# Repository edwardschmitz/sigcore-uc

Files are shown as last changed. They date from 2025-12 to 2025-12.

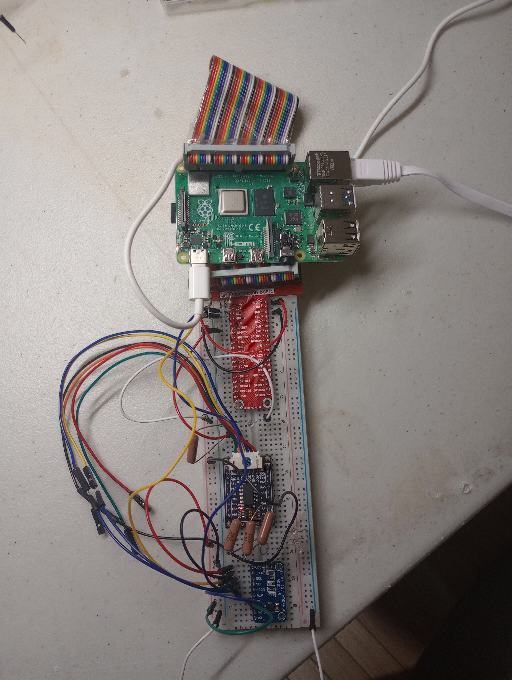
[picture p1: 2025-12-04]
docs/Images/test-pi-ADC.jpg

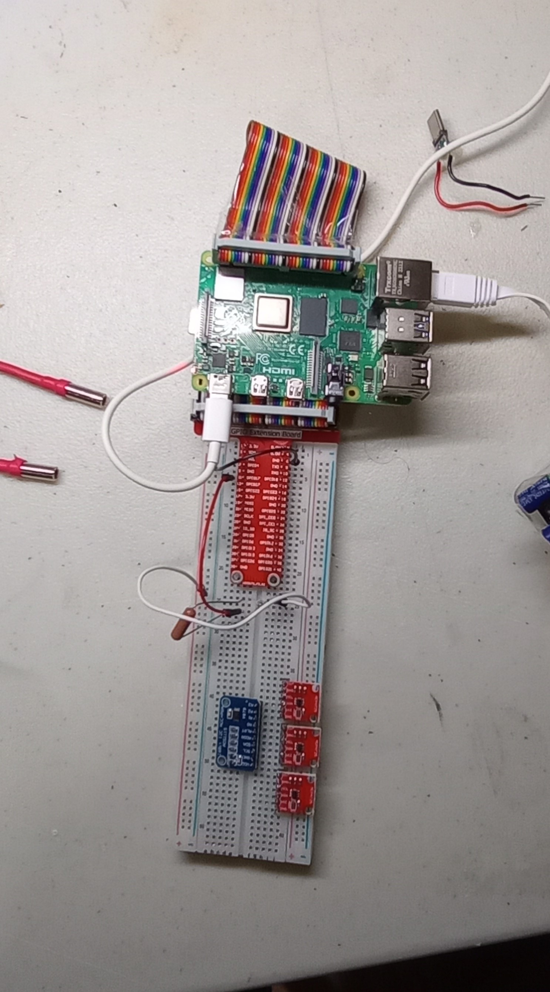
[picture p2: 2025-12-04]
docs/Images/pi-setup.jpg

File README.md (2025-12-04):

# SigCore UC – Universal Controller

**Status:**    In Development  
**Version:**   revA (prototype phase)  
**Runs on:**   Raspberry Pi OS (64-bit) with a .NET 8-based server and a C#/WPF Control Panel for Windows.

SigCore UC is a modular, high-precision universal I/O controller designed for engineers, developers, and integrators working in automation, control systems, and experimentation.

It supports a broad range of analog, digital, and current-loop signals, and is built to be both powerful and transparent—from PCB to Python.

---

## Key Features

- **Analog Inputs**
  - Millivolt to 10V input range
  - 4–20 mA loop support
  - Configurable filtering and calibration
- **Digital Inputs**
  - Logic level support from 3V to 30V
  - Built-in protection and detection
- **Relay Outputs**
  - High-current mechanical and solid-state options
  - Default-state configuration and software override
- **Analog Outputs**
  - Voltage and PWM output modes
- **Communication**
  - Ethernet 
  - Modbus and Web API integration
- **Extensibility**
  - Python and C# libraries
  - Firmware auto-update

---

## License

[MIT License](LICENSE) — open for inspection, modification, and contribution.

---

## About This Repo

SigCore UC is the successor to the [D88A42 Prototype](https://github.com/edwardschmitz/D88A42-Prototype).  
It brings forward lessons learned and raises the ceiling for custom I/O control systems.

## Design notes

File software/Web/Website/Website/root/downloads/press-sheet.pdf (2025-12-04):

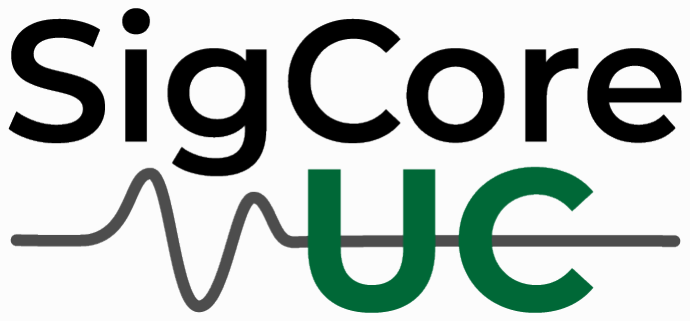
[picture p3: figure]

# Universal Controller

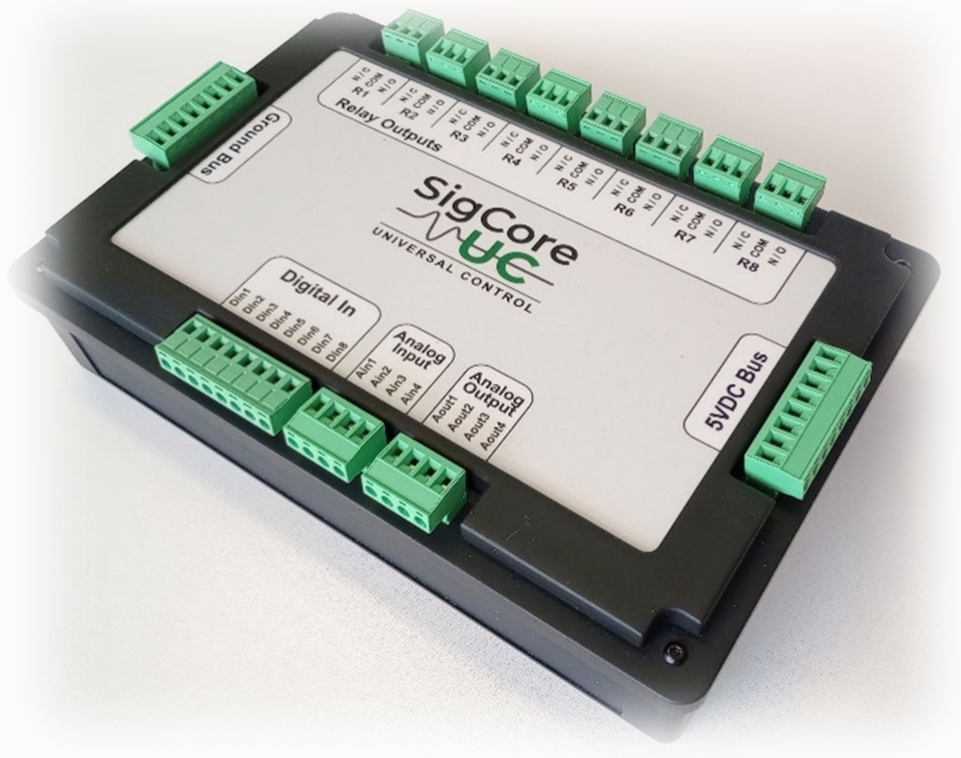
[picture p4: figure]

## A Complete Industrial Control and Data Collection System

SigCore UC is a fully functional industrial control and data collection system. Unlike development boards or expansion modules, SigCore UC is a complete, ready-to-deploy solution — combining rugged hardware with powerful software in one package.
- 8 Relay Outputs – switch equipment and high-current loads
- 8 Universal Digital Inputs – ON: 2–24 VDC, OFF: 0–0.5 VDC
- 4 Calibrated Analog Inputs – voltage or current, with filtering and engineering units
- 4 Analog Outputs – voltage or PWM
- Built-in PID Control Loops – no extra coding required
- Modbus TCP Server – plus .NET and Python libraries
- Control Panel Software – full operational control, including PID settings
- Data Logging – record process data for analysis and optimization Evaluation units are available now.
For review samples, specs, and high-resolution images, please contact: Edward Schmitz
■ en Z em | SigCore UC
■ edwardschmitzsoftware@hotmail.com
■ 805-650-2101
■ https://sigcoreuc.com
________________________________________________________________________ sigcoreuc.com

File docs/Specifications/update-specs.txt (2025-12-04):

REQUIREMENTS OF THE AUTO-UPDATE SYSTEM
=======================================

A. BUILDER (PC-side)
--------------------

A1. Packaging
    - A working SCU archive creator exists.
    - Files are copied into the package from the update source directory.
    - SCU format is implemented: header + file entries + data blocks.
    - Permissions may or may not be preserved depending on OS behavior.
    - Current implementation appears stable but not fully validated.

A2. Manifest Generation
    - Manifest.json is produced.
    - It includes:
        - hardware_rev
        - latest_version
        - versions array
        - SHA-256 hash
        - signature (string produced by builder)
        - URL for update download
    - Manifest.sig is produced using the private key.
    - Manifest fingerprints and version selection appear correct.

A3. Signing
    - SCU file is signed with the private key.
    - Manifest is signed with the private key.
    - Signatures are stored next to their files.
    - Validation steps have not yet been fully tested against corrupted files.

A4. Output Structure
    - Builder writes output into: update/<revision>/<version>/
    - Folder contains:
        - update.scu
        - update.scu.sig
        - manifest.json
        - manifest.sig
    - No automatic cleanup or pruning of old versions exists.

A5. Reliability
    - Builder behaves consistently for known inputs.
    - No automated tests are in place.
    - Error-handling is minimal but functional.
    - Previous versions are not overwritten.

B. LAUNCHER (Pi-side)
----------------------

B1. Update Detection
    - Reads identity.json to determine hardware revision.
    - Constructs URL based on revision.
    - Retrieves manifest.json from remote server.
    - Compares local version vs manifest.latest_version.
    - Currently supports manual testing but not scheduled execution.

B2. Manifest Verification
    - Public key is stored on the Pi.
    - Manifest.sig verification logic is implemented.
    - Verification must pass before continuing.
    - No fallback behavior is defined for malformed manifests.

B3. Download and Validation
    - Launcher downloads update.scu only when needed.
    - SCU signature verification exists.
    - SCU file is checked against manifest hash.
    - Error handling exists but needs strengthening.

B4. Extract and Stage
    - Staging directory: /opt/sigcore/staging
    - Extracts SCU contents into staging.
    - Directory structure is preserved.
    - Validation of required files is not fully implemented.

B5. Apply Update
    B5a. System Prep
        - Stops SigCore Server and WebBridge manually (logic exists but is not final).
        - Remounts filesystem read-write.
        - No versioned backup directory exists yet, but placeholder logic is in place.

    B5b. File Deployment
        - Copies binaries to /opt/sigcore/.
        - Copies website files to /var/www/html/.
        - Writes new version to identity.json.
        - Some deployments still done with shell commands wrapped in code.

    B5c. Cleanup
        - Remounts filesystem read-only.
        - Restarts SigCore Server and WebBridge.
        - Staging directory removed on success.

B6. Failure Handling
    - Verification failures stop the update.
    - Apply failures cause early-return behavior.
    - Automated rollback logic is not fully implemented.
    - System safety behavior has not been fully validated.

B7. Logging
    - Console logging exists.
    - No persistent log file yet.
    - Intended future path: /var/log/sigcore/update.log.

B8. Manual Control
    - Command-line “run once” behavior works now.
    - No CLI arguments for status yet.
    - Launcher is not yet registered as a system service.

SIGCORE UPDATE BUILDER — FILE PURPOSES
======================================

A. ROOT BUILDER FILES
---------------------

Program.cs
    - Entry point for the SigCore Update Builder.
    - Validates that 4 arguments were provided:
        - revision
        - version
        - notes
        - private_key.pem
    - Instantiates UpdateBuilder with the given parameters.
    - Executes builder.Run() to perform the entire build process.
    - Contains no build logic — purely orchestration.

UpdateBuilder.cs
    - Central orchestrator for building a complete SCU-based update release.
    - Responsibilities:
        - Stores revision, version, notes, and private key path.
        - Defines absolute paths for:
            - sigcoreserver executable
            - WebBridge executable
            - local website root directory
            - public key for fingerprinting
        - Creates a temporary build root (temp directory).
        - Creates destination paths:
            - /opt/sigcore
            - /var/www/html
        - Copies:
            - sigcoreserver → opt/sigcore/sigcoreserver
            - WebBridge → opt/sigcore/WebBridge
            - Website contents → var/www/html/**
        - Creates staging output directory:
            C:\Users\eddie\OneDrive\Documents\sigcore\updates\<revision>\<version>\
        - Invokes ScuArchive.Create() to produce update.scu
        - Extracts update.scu into a verify_extract/ folder for self-validation
        - Signs update.scu into update.scu.sig
        - Constructs manifest.json containing:
            - hardware_rev
            - latest_version
            - public_key_fingerprint
            - versions array (with all metadata)
        - Saves manifest.json
        - Signs manifest.json into manifest.sig
        - Prints summary of generated files
    - Includes helpers:
        - CopyFile()
        - CopyDirectory()
    - Entire update packaging workflow lives here.

B. COMMON "UPDATE" LIBRARY FILES
--------------------------------

FingerprintHelper.cs
    - Computes a SHA-256 fingerprint of a PEM public key.
    - Loads RSA key from PEM.
    - Exports the DER-encoded SubjectPublicKeyInfo block.
    - Hashes the DER with SHA-256.
    - Returns lowercase hex fingerprint string.
    - Used to embed public key fingerprint inside manifest.json.
    - Prints the fingerprint to console for debug visibility.

HashHelper.cs
    - Provides SHA-256 hashing utilities.
    - Sha256File(path)
        - Opens file as a stream.
        - Hashes contents.
        - Returns lowercase hex SHA-256 string.
    - Sha256Bytes(data)
        - Hashes in-memory byte array.
    - Internal BytesToHex()
        - Converts byte[] to lowercase hex.
    - Used for SCU archive hashing inside the manifest.

ManifestModel.cs
    - Full data model for manifest.json (serialized/deserialized via Newtonsoft.Json).
    - Top-level fields:
        - hardware_rev
        - latest_version
        - public_key_fingerprint
        - versions[] array
    - VersionEntry fields:
        - version
        - release_date
        - hash_sha256
        - signature (URL to update.scu.sig)
        - url (URL to update.scu)
        - notes
        - executables (list of files the launcher must make executable)
    - Methods:
        - Load(path)
        - Save(path)
    - Used directly by UpdateBuilder when constructing manifest.json.

ScuArchive.cs
    - Implements the SCU1 archive format used by SigCore updates.
    - Magic header: "SCU1"
    - Create(rootFolder, outputFile)
        - Scans all files under rootFolder (recursive)
        - Writes:
            - Magic ("SCU1")
            - File count
            - For each file:
                - Relative path (UTF-8 bytes)
                - Path length (ushort)
                - File length (ulong)
                - Raw file bytes
        - Ensures cross-platform safe relative paths (uses forward slashes)
    - Extract(scuFile, targetFolder)
        - Validates magic header
        - Reads file entries and size metadata
        - Recreates directory structure in targetFolder
        - Restores files exactly as archived
    - GetRelativePath()
        - Uses Uri logic to compute a clean platform-independent path
    - Used by the builder to package **and self-verify** update.scu.

SignatureHelper.cs
    - RSA signing and verification utilities for SCU and manifest.
    - SignFile(privateKeyPem, inputFile, signatureOutputFile)
        - Reads file data.
        - Produces RSA SHA-256 PKCS#1 signature.
        - Writes signature bytes to .sig file.
    - VerifyFile(publicKeyPem, inputFile, signatureFile)
        - Reads both data and signature.
        - Uses RSA public key to verify signature.
    - SignData / VerifyData
        - Core RSA signing logic.
    - LoadPrivateKeyFromPem()
        - Supports encrypted PEM (password currently hardcoded).
        - Supports unencrypted PEM.
    - LoadPublicKeyFromPem()
        - Loads RSA public key.
    - Entire cryptographic signing layer for SCU and manifest is here.

SIGCORE LAUNCHER — FILE PURPOSES
================================

A. DOWNLOAD AND VALIDATION COMPONENTS
-------------------------------------

ManifestDownloader.cs
    - Downloads manifest.json and manifest.sig from the update server.
    - Uses HttpClient to fetch both files as raw byte arrays.
    - Writes results to local disk paths provided by caller.
    - CancellationToken supported for clean shutdown.
    - No validation performed here — strictly a fetch utility.

ManifestValidator.cs
    - Fully validates a manifest + manifest.sig pair.
    - Steps:
        - Uses SignatureHelper.VerifyFile() to confirm manifest.sig is valid.
        - Loads manifest.json into ManifestModel.
        - Computes the fingerprint of the public key on the device.
        - Compares:
            - expectedFingerprint → from Launcher config / identity
            - actualFingerprint → recomputed from local public key
            - manifest.PublicKeyFingerprint → declared by the builder
        - All 3 must match.
    - Purpose:
        - Prevent tampering.
        - Ensure the manifest belongs to the correct hardware revision.
        - Ensure nobody swapped the keypair.

ScuVerifier.cs
    - Responsible for downloading + verifying update.scu and update.scu.sig.
    - DownloadAsync():
        - Downloads SCU and its corresponding signature.
    - Validate():
        - Verifies SHA-256 hash matches manifest entry.
        - Verifies signature matches local public key.
    - Returns boolean success/failure.
    - This is the integrity gate before extraction or installation.

B. INSTALLATION COMPONENTS
--------------------------

AtomicInstaller.cs
    - Applies a verified SCU update safely and atomically.
    - Steps:
        - Deletes existing extractRoot if present.
        - Extracts SCU using ScuArchive.Extract().
        - Locates extracted:
            - opt/sigcore contents
            - var/www/html contents
        - Installs files into live filesystem using atomic replace logic.

    - InstallDirectoryAtomic():
        - Iterates all files under src directory.
        - Maps each to corresponding path under dest.
        - Creates dirs as needed.
        - Uses AtomicReplaceFile() for each file.

    - AtomicReplaceFile():
        - Writes new file as *.new
        - Renames old file to *.bak if present
        - Moves *.new → final filename
        - Removes *.bak if everything succeeded
    - Goal:
        - Never leave corrupted partial files, even after power loss.

C. LOCAL STATE COMPONENTS
-------------------------

InstalledVersionReader.cs
    - Simple utility to read:
        - revision.txt
        - version.txt
    - If file missing:
        - Revision: returns "unknown"
        - Version: returns "0.0.0"
    - Used by UpdateSupervisor / Launcher to compare local state vs manifest.

D. MAIN RUNTIME / PROCESS SUPERVISION
-------------------------------------

Launcher.cs
    - Main runtime supervisor for:
        - SigCoreServer process
        - WebBridge process
    - Fields:
        - serverExe = /opt/sigcore/sigcoreserver
        - bridgeExe = /opt/sigcore/WebBridge
        - revisionPath, versionPath
        - manifest URLs (currently hardcoded to revA)
        - public-key path
        - expectedFingerprint (static for now)
    - RunAsync():
        - Runs update supervisor first.
        - Starts both processes.
        - Enters supervision loop:
            - Every 2 seconds, checks if each process is alive.
            - Restarts dead processes automatically.
        - On token cancellation:
            - Stops both processes gracefully.
    - StartServer() / StartBridge():
        - Launch processes with redirected output.
    - ProcessAlive():
        - Safe check ensuring process hasn't crashed.
    - StopAsync():
        - Kills both server and bridge.
    - Primary role:
        - Keep SigCoreServer and WebBridge alive.
        - Ensure updates are applied before processes start.

E. LAUNCHER VARIANT (OLDER DESIGN)
----------------------------------

LauncherManager.cs
    - An older, alternative launcher architecture.
    - Not used by the current Program.cs entry point.
    - Responsibilities:
        - Loads identity.json
        - Derives revision + version from identity
        - Validates public key presence
        - Invokes UpdateSupervisor with revision-based URLs
        - Starts SigCoreServer then WebBridge
        - Handles Ctrl+C shutdown
        - Terminates both processes on exit
    - Contains:
        - IdentityModel / HardwareInfo / SoftwareInfo inline classes
    - Notes:
        - This may be retired or folded into the new Launcher class.
        - Duplicates responsibilities found in Launcher.cs
        - May be a leftover from a previous architecture.

F. ENTRY POINT
--------------

Program.cs
    - Entry point for the launcher service.
    - Writes startup banner.
    - Registers signal handlers (Ctrl+C, ProcessExit).
    - Allocates CancellationTokenSource.
    - Instantiates Launcher and calls RunAsync().
    - On exceptions:
        - Outputs diagnostic information.
    - On shutdown:
        - Cancels token and allows launcher to stop server + bridge.
    - Contains no update or process logic — purely coordinator.

G. UPDATE EXECUTION LAYER
-------------------------

UpdateRunner.cs
    - Executes the full update cycle once an update has been approved.
    - Responsibilities:
        - Downloads manifest.json + manifest.sig into /tmp/SigCoreUpdate
        - Validates the manifest via ManifestValidator
        - Parses manifest to extract latest version info
        - Downloads update.scu and update.scu.sig
        - Validates:
            - SHA-256 hash
            - RSA signature
        - Extracts update.scu into /tmp/SigCoreUpdateExtract
        - Applies update via AtomicInstaller.Install()
        - Applies executable permissions to any paths listed in manifest.Executables
    - Constructor sets:
        - temp file paths
        - extractRoot for SCU extraction
        - optTarget (e.g. /opt/sigcore)
        - webTarget (e.g. /var/www/html)
    - RunAsync():
        - Returns true on success, false on failure.
        - Primary single-shot update installer.

H. UPDATE SUPERVISION AND DECISION LOGIC
----------------------------------------

UpdateSupervisor.cs
    - Higher-level orchestrator that decides whether an update is needed.
    - Responsibilities:
        - Reads installed revision.txt and version.txt using InstalledVersionReader
        - Downloads manifest.json + manifest.sig
        - Validates manifest via ManifestValidator
        - Uses UpdateDecisionEngine to decide whether update should occur
            - NoUpdate
            - WrongHardwareRevision
            - ManifestInvalid
            - UpdateAvailable
        - If update required:
            - Creates UpdateRunner and executes RunAsync()
        - Logs all decisions
    - Inputs:
        - manifest URLs
        - public key path
        - expected fingerprint
        - installed revision/version files
        - target installation directories
    - Run order:
        - Validate manifest
        - Evaluate decision
        - If update needed, run updater
        - Return true on success or “no update required”
        - Return false on hardware mismatch or failure

UpdateDecisionEngine.cs
    - Decides whether an update is required.
    - Conditions checked:
        - manifest is null → ManifestInvalid
        - hardware revision mismatch → WrongHardwareRevision
        - manifest contains no versions → ManifestInvalid
        - version comparison:
            - installedVersion >= latestVersion → NoUpdate
            - installedVersion < latestVersion → UpdateAvailable
    - Uses VersionComparer to compare semantic-like version strings.
    - Pure logic only — no file I/O.

I. VERSION COMPARISON AND VERSION STAMPING
------------------------------------------

VersionComparer.cs
    - Parses version strings like "1.2.3.4" or "1.0" or "2".
    - Splits on "." and compares each numeric segment.
    - Missing segments treated as zero.
    - Non-numeric segments treated as zero.
    - Returns:
        - -1 if a < b
        - +1 if a > b
        - 0 if equal
    - Used by UpdateDecisionEngine.

VersionStampWriter.cs
    - Writes revision.txt and version.txt *safely* after successful installation.
    - WriteInstalledVersion():
        - Writes both revision and version using atomic-safe logic.
    - WriteSafe():
        - Writes *.new file
        - Moves old file to *.bak
        - Renames *.new to official path
        - Cleans *.bak
    - Ensures partial writes cannot corrupt version tracking.

J. SYSTEMD SERVICE CONTROL
--------------------------

ServiceController.cs
    - Utilities for controlling Linux systemd services.
    - Provides:
        - StopService(name)
        - StartService(name)
        - IsActive(name)
        - IsInactive(name)
    - All functions wrap systemctl commands via /bin/bash.
    - Used for service-based architectures where SigCoreServer/WebBridge may run as systemd units instead of standalone processes.
    - Currently not used in the new Launcher.cs but remains part of legacy support.

K. SUMMARY OF THE UPDATE PIPELINE (FOR CROSS-FILE CONTEXT)
-----------------------------------------------------------

    1. Launcher.cs starts → calls UpdateSupervisor
    2. UpdateSupervisor:
        - Reads installed version/revision
        - Downloads + validates manifest
        - Uses UpdateDecisionEngine to decide if update needed
    3. If update required:
        - Creates UpdateRunner
    4. UpdateRunner:
        - Downloads SCU + sig
        - Validates both
        - Extracts SCU
        - Installs via AtomicInstaller
        - Ensures executables are +x
    5. VersionStampWriter writes new version/revision
    6. Launcher starts services (server + bridge)

SIGCORE AUTO-UPDATE SYSTEM — LIVING SPECIFICATION
=================================================

A. PURPOSE AND GOALS
--------------------
- Provide authenticated, atomic, hardware-aware updates for SigCore UC.
- Ensure updates cannot brick the device.
- Ensure updates cannot be spoofed or tampered with.
- Ensure the update runs BEFORE Server and WebBridge start.
- Ensure Pi runtime always has verified, latest valid software.
- Support offline-safe extraction and atomic replacement.

B. MAJOR COMPONENTS
-------------------
- Builder (Windows): packages, signs, and publishes updates.
- SCU Archive Format: custom binary package containing all update files.
- Manifest: JSON definition describing update metadata and security.
- Launcher (Pi): performs update-check, validation, installation, and process supervision.
- UpdateSupervisor: decision logic for whether and when to update.
- UpdateRunner: performs actual installation.
- AtomicInstaller: performs atomic file replacement.
- Version tracking: revision.txt and version.txt.

C. FILE PATHS (PI SIDE)
-----------------------
- Executables:
    - /opt/sigcore/sigcoreserver
    - /opt/sigcore/WebBridge
- Keys:
    - /opt/sigcore/keys/sigcore_public.pem
- Installed version state:
    - /opt/sigcore/version.txt
    - /opt/sigcore/revision.txt
- Website:
    - /var/www/html
- Temp update locations:
    - /tmp/SigCoreUpdate
    - /tmp/SigCoreUpdateExtract

D. SCU ARCHIVE FORMAT
---------------------
- Magic header: "SCU1"
- uint32: file count
- Per file:
    - ushort: UTF-8 path length
    - bytes: UTF-8 path
    - ulong: file size
    - raw file bytes
- Paths stored normalized with forward slashes.
- Archive contains:
    - opt/sigcore/*    (server, bridge, identities, keys, version files)
    - var/www/html/*   (website)
- Extraction reproduces exact tree.

E. MANIFEST FORMAT
------------------
- hardware_rev (string)
- latest_version (string)
- public_key_fingerprint (hex SHA-256 of DER key)
- versions[]:
    - version
    - release_date
    - hash_sha256 (of update.scu)
    - signature (URL to update.scu.sig)
    - url (URL to update.scu)
    - notes
    - executables[] (files requiring chmod +x)

F. SECURITY MODEL
-----------------
- Builder holds private key (never distributed).
- Pi holds public key in /opt/sigcore/keys/.
- Builder signs:
    - manifest.json
    - update.scu
- Launcher validates:
    - manifest.sig → matches manifest
    - manifest.PublicKeyFingerprint → matches local public key fingerprint
    - SCU hash → matches manifest.hash_sha256
    - SCU signature → matches public key
- Update is rejected if:
    - signature mismatch
    - hash mismatch
    - fingerprint mismatch
    - wrong hardware revision

G. UPDATE DECISION LOGIC
------------------------
- Read installed:
    - revision.txt
    - version.txt
- Download manifest + sig.
- Validate manifest.
- Compare installedRevision vs manifest.hardware_rev:
    - mismatch → reject update.
- Compare installedVersion vs latestVersion using VersionComparer:
    - installed >= latest → no update.
    - installed < latest → update available.

H. UPDATE PROCESS FLOW (PI SIDE)
--------------------------------
1. Launcher starts.
2. Calls UpdateSupervisor.
3. UpdateSupervisor:
    - Reads installed version/revision.
    - Downloads manifest + sig.
    - Validates manifest.
    - Applies UpdateDecisionEngine.
4. If update needed:
    - Create UpdateRunner.
    - Download SCU + sig.
    - Validate hash + signature.
    - Extract SCU into /tmp/SigCoreUpdateExtract.
    - AtomicInstaller.Install() replaces live files.
    - Apply executable flags.
    - Write new version.txt and revision.txt.
5. Launcher starts processes.

I. ATOMIC INSTALLATION RULES
----------------------------
- All installation done under extractRoot.
- For each file:
    - dest.new → write
    - dest.bak → old (if exists)
    - dest.new → dest (move)
    - delete dest.bak
- Ensures:
    - No partial files
    - No corruption from sudden shutdown
    - Every update is all-or-nothing

J. RUNTIME PROCESS SUPERVISION
------------------------------
- Launcher starts:
    - sigcoreserver
    - WebBridge
- Checks every ~2 seconds:
    - if process dead → restart
- On shutdown:
    - kill both processes safely.

K. BUILDER INPUTS & OUTPUTS
----------------------------
Inputs:
    - revision
    - version
    - notes
    - private_key.pem
    - paths to:
        - sigcoreserver binary
        - WebBridge binary
        - website root

Outputs:
    - update.scu
    - update.scu.sig
    - manifest.json
    - manifest.sig

Directory layout:
    update/<revision>/<version>/update.scu
    update/<revision>/<version>/update.scu.sig
    update/<revision>/<version>/manifest.json
    update/<revision>/<version>/manifest.sig

L. VERSIONING RULES
-------------------
- Versions are dot-separated numerics: A.B.C.D
- Extra segments allowed.
- Missing segments treated as zero.
- Non-numeric segments treated as zero.
- VersionComparer decides:
    - <0: installed older
    - =0: equal
    - >0: installed newer

M. CODEBASE SUMMARY (BUILDER)
------------------------------
- Program.cs
    - CLI entry point.
- UpdateBuilder.cs
    - Master build orchestrator.
- FingerprintHelper.cs
    - Public key fingerprint generation.
- HashHelper.cs
    - SHA-256 hashing utilities.
- ManifestModel.cs
    - Manifest JSON schema.
- ScuArchive.cs
    - SCU1 binary packaging/extraction.
- SignatureHelper.cs
    - RSA signing/verification utilities.

N. CODEBASE SUMMARY (LAUNCHER)
------------------------------
- ManifestDownloader.cs
    - Downloads manifest + signature.
- ManifestValidator.cs
    - Validates manifest.signature + fingerprint.
- ScuVerifier.cs
    - Downloads + validates SCU.
- InstalledVersionReader.cs
    - Reads installed version/revision.
- AtomicInstaller.cs
    - Atomic installation logic.
- UpdateDecisionEngine.cs
    - Determines whether update needed.
- VersionComparer.cs
    - Compares semantic versions.
- VersionStampWriter.cs
    - Atomically writes installed version files.
- UpdateSupervisor.cs
    - High-level update logic: decide → run.
- UpdateRunner.cs
    - Performs actual update install.
- ServiceController.cs
    - systemd control utilities (not used in current Launcher).
- Launcher.cs
    - Starts, supervises SigCoreServer + WebBridge.
- Program.cs (launcher)
    - Entry point, shutdown management.

O. REQUIRED ENVIRONMENT
-----------------------
- Linux ARM64 (Pi 4 or Pi 5).
- Read-only root filesystem during operation (future final state).
- Ability to remount rw during update installation (future).
- /opt/sigcore owned by runtime user.
- Web server serves /var/www/html.

P. OPERATIONAL GUIDANCE
-----------------------
- To trigger update manually:
    - Restart launcher.
- To review update errors:
    - Console logs now; future: /var/log/sigcore/update.log.
- To replace public key:
    - Update public key file.
    - Update fingerprint in the builder.
    - Push new manifest with updated fingerprint.
- To test updates:
    - Run builder.
    - Upload update folder to server.
    - Restart launcher on Pi.

Q. FUTURE IMPROVEMENTS
----------------------
- Centralized logging.
- Rollback mechanism.
- Configurable URLs for manifest.
- Non-hardcoded fingerprint.
- Removal of deprecated LauncherManager.
- Option for daily scheduled update checks (service timer).
- Read-only root filesystem enforcement.

ASSISTANT GROUND RULES
----------------------

- Do not use var in any C# code. All types must be explicitly declared.
- Do not insert comments into source code unless explicitly instructed.
- Do not invent or assume the contents of any class, method, or structure. Ask the user when information is missing.
- Do not change method signatures, constructors, or argument structures unless the fix requires it and the user approves.
- Apply fixes one at a time. Do not bundle multiple fixes.
- All code changes must be precise, minimal, and limited to the stated fix.
- Do not alter logging, console output, or filenames unless explicitly instructed.
- Do not assume any library method or helper exists unless the user has shown it. Request missing definitions.
- Do not introduce new dependencies, namespaces, or classes unless explicitly requested.
- When providing updated code files, provide the complete corrected file unless the user requests a fragment.
- Follow sequencing instructions exactly as given.
- Do not reinterpret, generalize, or expand user instructions.
- Do not provide meta-explanations unless requested.
- Apply all stated code-style rules consistently.
- Ask when uncertain.
- When the user requests “text only format,” the assistant must output plain text only,
  without commentary, without markup, without embellishment, and without any structure
  beyond exactly what the user requested and in a code section.

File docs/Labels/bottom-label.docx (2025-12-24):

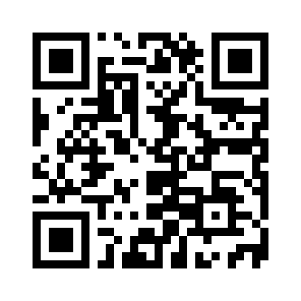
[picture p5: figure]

# SigCore UC

## en Z em Product

Getting Started: | https://sigcoreuc.com/getting-started.html
MAC Address: | 88:A2:9E:3A:0E:C0
Serial Number: | SCUC-000020
Hostname: | scuc-000020
Revision: | revA

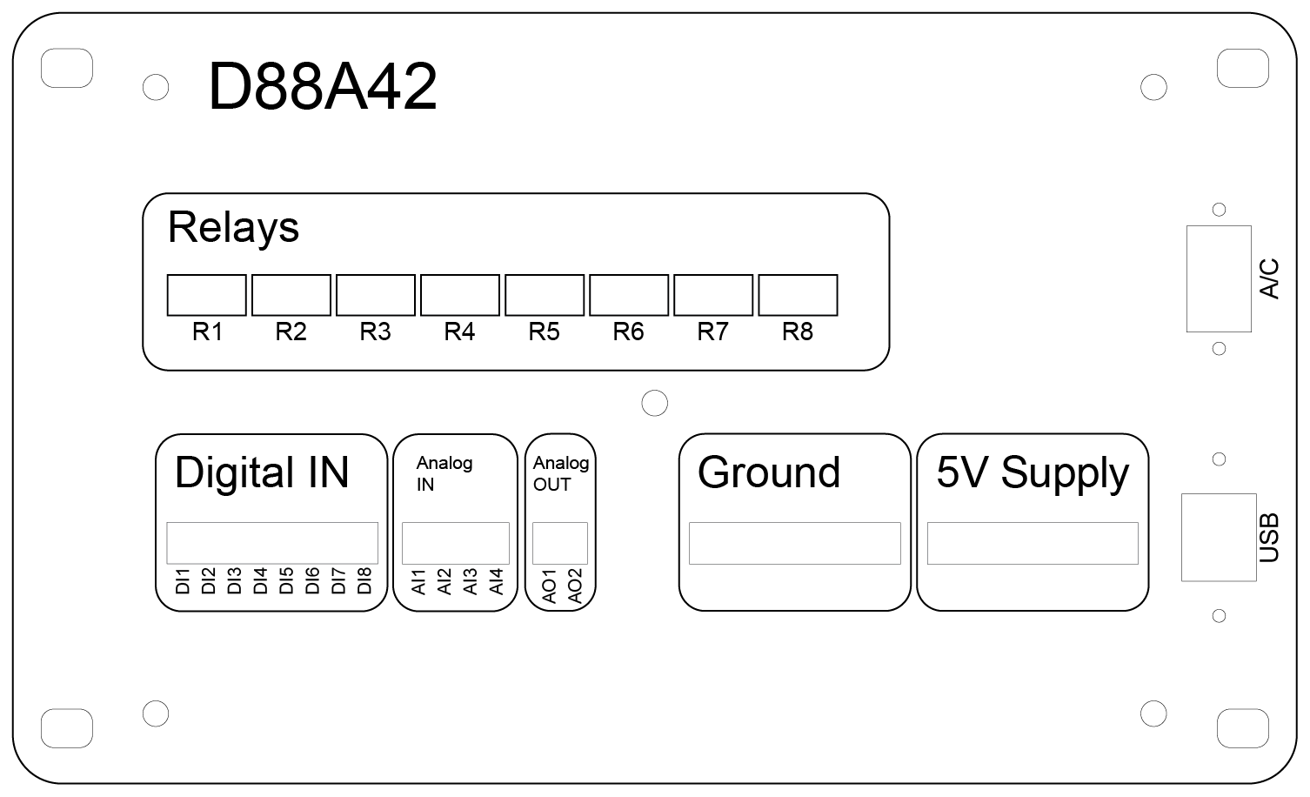
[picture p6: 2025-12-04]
software/Web/Website/Website/root/images/LidDesign.png

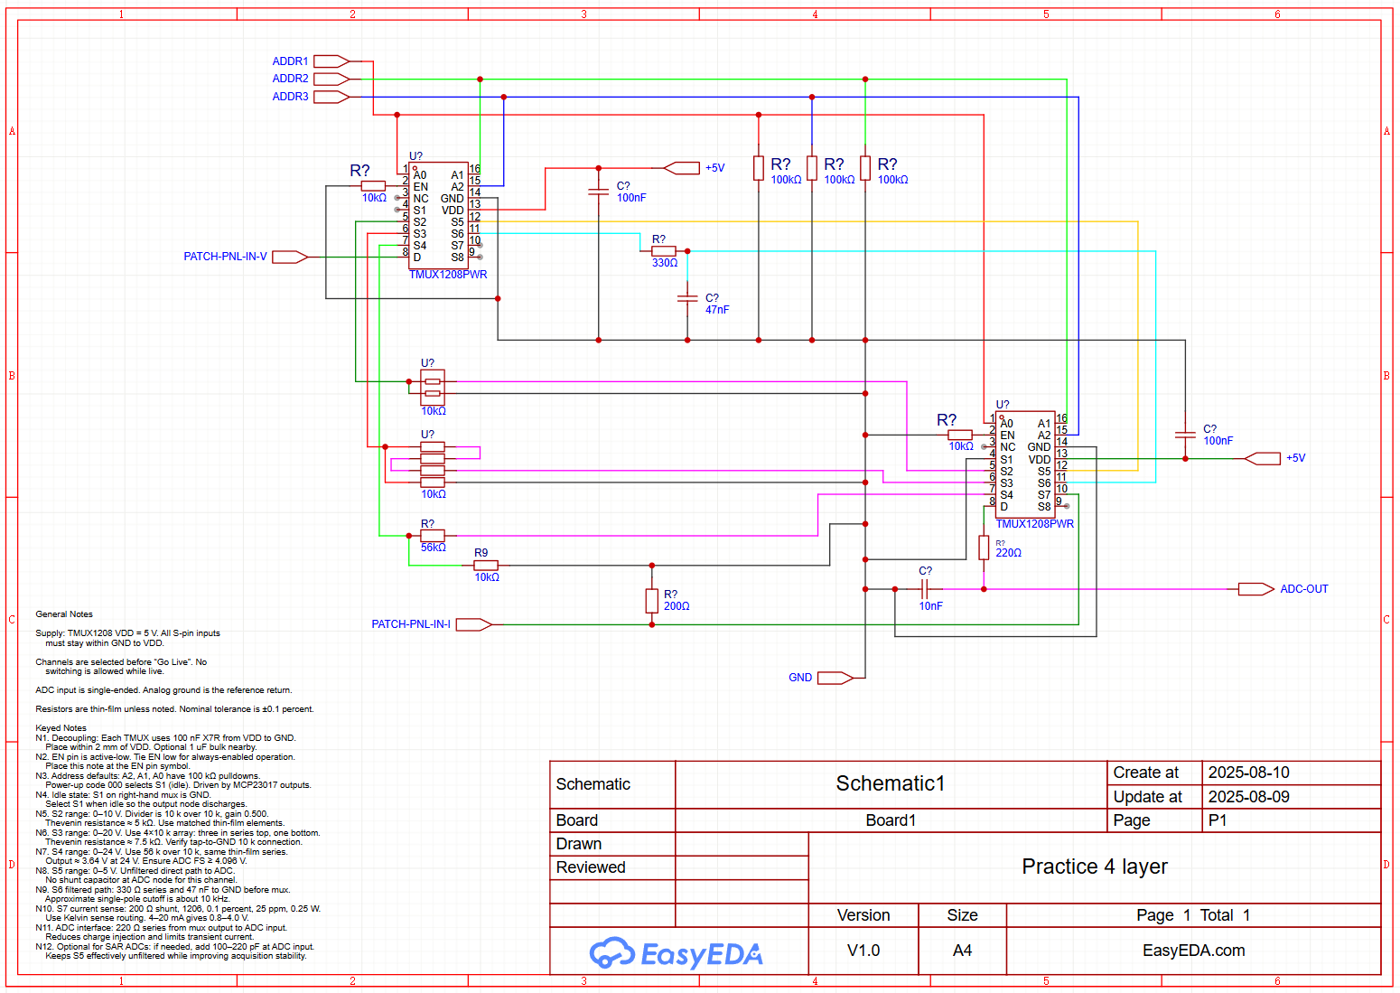
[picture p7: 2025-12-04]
docs/Drawings/sketches/analog-in-circuit-design.png

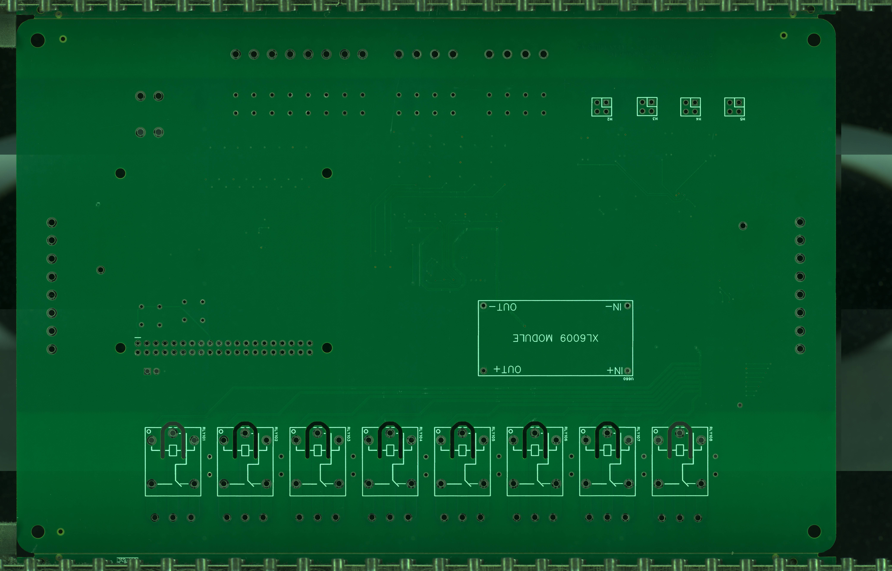
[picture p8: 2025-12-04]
hardware/Review/SMT025090962540_B_20250915064155.jpg

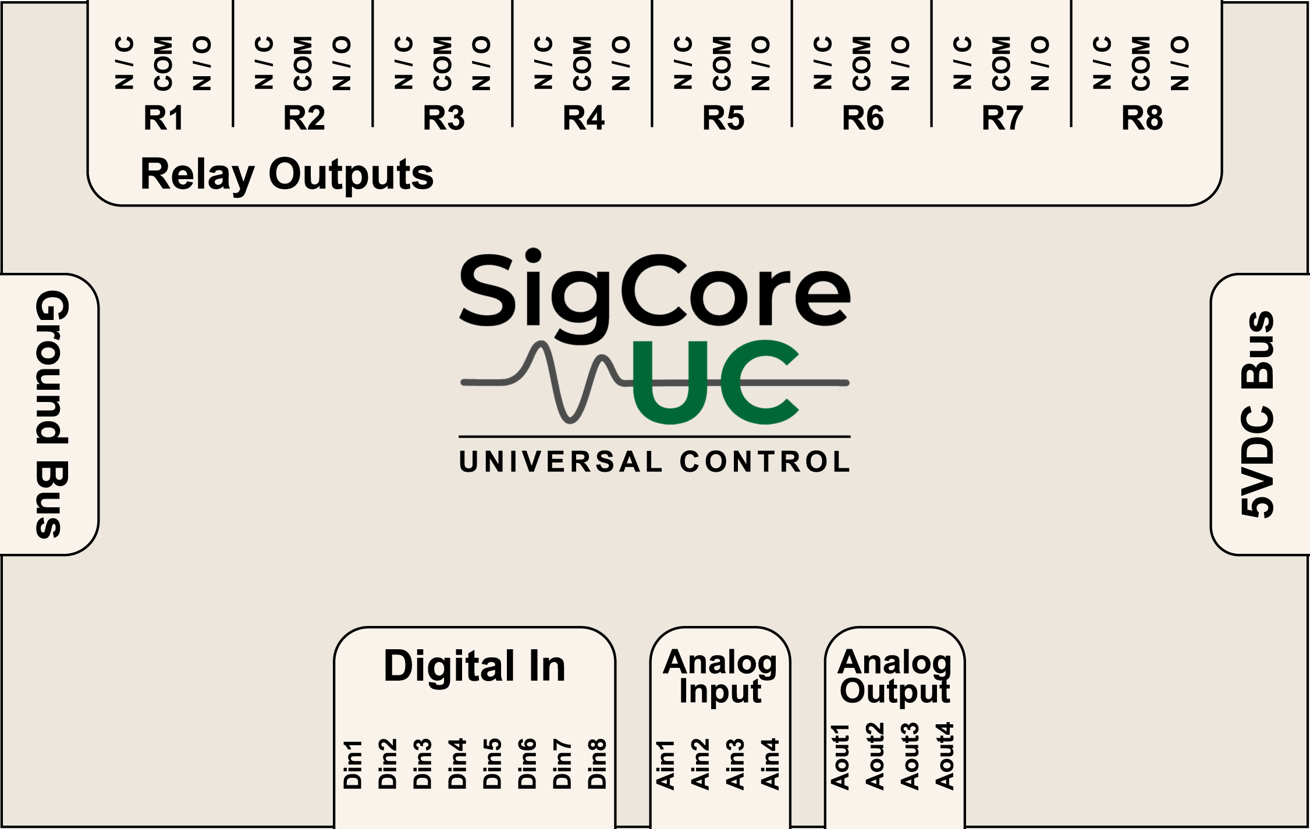
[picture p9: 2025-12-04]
hardware/overlay/top-overlay-outlines.png

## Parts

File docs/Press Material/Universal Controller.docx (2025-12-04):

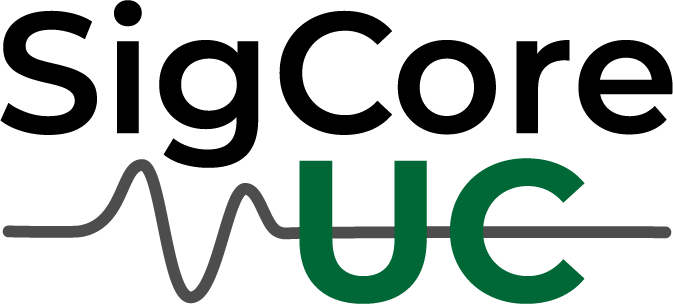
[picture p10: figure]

# Universal Controller

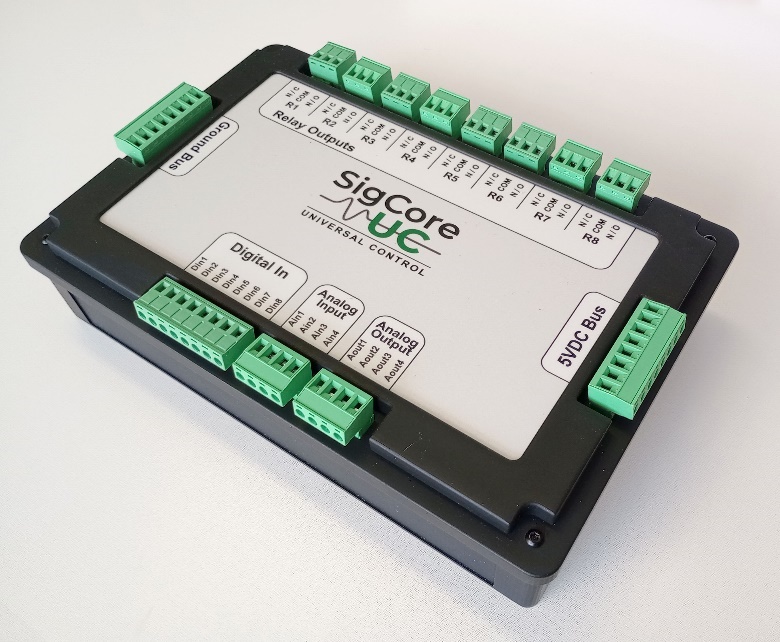
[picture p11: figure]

A Complete Industrial Control and Data Collection System

SigCore UC is a fully functional industrial control and data collection system. Unlike development boards or expansion modules, SigCore UC is a complete, ready-to-deploy solution — combining rugged hardware with powerful software in one package.

- 8 Relay Outputs – switch equipment and high-current loads
- 8 Universal Digital Inputs – ON: 2–24 VDC, OFF: 0–0.5 VDC
- 4 Calibrated Analog Inputs – voltage or current, with filtering and engineering units
- 4 Analog Outputs – voltage or PWM
- Built-in PID Control Loops – no extra coding required
- Modbus TCP Server – plus .NET and Python libraries
- Control Panel Software – full operational control, including PID settings
- Data Logging – record process data for analysis and optimization

Evaluation units are available now.

For review samples, specs, and high-resolution images, please contact:

Edward Schmitz
■ en Z em | SigCore UC
■ edwardschmitzsoftware@hotmail.com
■ 805-650-2101
■ https://sigcoreuc.com

________________________________________________________________________
sigcoreuc.com

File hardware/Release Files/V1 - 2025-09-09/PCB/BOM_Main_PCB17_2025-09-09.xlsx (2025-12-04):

No. | Quantity | Comment | Designator | Footprint | Value | Manufacturer Part | Manufacturer | Supplier Part | Supplier
1 | 17 | 100nF | C1,C300,C302,C303,C406,C601,C603,C610,C620,C633,C636,C638,C640,C642,C645,C646,C647 | C0603 | 100nF | CC0603KRX7R9BB104 | YAGEO(国巨) | C14663 | LCSC
2 | 6 | 10uF | C2,C3,C4,C5,C8,C9 | C0603 | 10uF | C0603B106M007T | IHHEC(禾伸堂) | C7094065 | LCSC
3 | 2 | 100nF | C6,C7 | C0603 | 100nF | 0603X7R104K500NT | AIDE(爱迪电容) | C48579281 | LCSC
4 | 4 | 100uF | C10,C11,C12,C13 | C0805 | 100uF | HGC0805R5107M6R3NSLJ | Chinocera(华瓷) | C49333236 | LCSC
5 | 1 | 470uF | C14 | CAP-SMD_BD6.3-L6.6-W6.6-LS7.6-RD | 470uF | RVT1C471M0607 | ROQANG(容强) | C2977552 | LCSC
6 | 1 | 1uF | C301 | C0603 | 1uF | CL10A105KB8NNNC | SAMSUNG(三星) | C15849 | LCSC
7 | 4 | 100pF | C629,C630,C631,C632 | C0603 | 100pF | TCC0603COG101J500CT | CCTC(三环) | C344186 | LCSC
8 | 1 | 100uF | C635 | CAP-SMD_BD6.3-L6.6-W6.6-LS7.2-FD | 100uF | MVK 35V100 M 6.3*8 | SAMYOUNG(韩国三莹) | C350012 | LCSC
9 | 4 | 47nF | C637,C639,C641,C643 | C0603 | 47nF | CL10B473KB8NNNC | SAMSUNG(三星) | C1622 | LCSC
10 | 1 | 10uF | C644 | C0805 | 10uF | CGA0805X5R106K350MT | HRE(芯声) | C6119888 | LCSC
11 | 1 | B5819W SL | D451 | SOD-123_L2.7-W1.6-LS3.7-RD-1 |  | B5819W SL | CJ(江苏长电/长晶) | C8598 | LCSC
12 | 4 | BAT54 | D452,D453,D454,D455 | SOT-23-3_L2.9-W1.6-P1.90-LS2.8-BR |  | BAT54 | TWGMC(迪嘉) | C47283675 | LCSC
13 | 8 | XL-1608UBC-04 | LED108,LED110,LED112,LED113,LED114,LED115,LED116,LED117 | LED0603-RD_BLUE |  | XL-1608UBC-04 | XINGLIGHT(成兴光) | C965807 | LCSC
14 | 8 | MMBT3904 | Q401,Q402,Q403,Q404,Q405,Q406,Q407,Q408 | SOT-23-3_L2.9-W1.3-P1.90-LS2.4-BR |  | MMBT3904 | DOWO(东沃) | C22374713 | LCSC
15 | 8 | 100kΩ | R100,R101,R102,R104,R105,R106,R107,R108 | R0603 | 100kΩ | 0603WAF1003T5E | UNI-ROYAL(厚声) | C25803 | LCSC
16 | 8 | 1kΩ | R110,R114,R115,R116,R117,R118,R119,R120 | R0603 | 1kΩ | 0603WAF1001T5E | UNI-ROYAL(厚声) | C21190 | LCSC
17 | 2 | 10kΩ | R121,R401 | R0603 | 10kΩ | FRC0603J103 TS | FOJAN(富捷) | C2930027 | LCSC
18 | 8 | 150kΩ | R403,R710,R713,R716,R719,R722,R725,R728 | R0603 | 150kΩ | FRC0603F1503TS | FOJAN(富捷) | C2906993 | LCSC
19 | 8 | 470kΩ | R404,R711,R714,R717,R720,R723,R726,R729 | R0603 | 470kΩ | RC0603FR-07470KL | YAGEO(国巨) | C114622 | LCSC
20 | 8 | 24kΩ | R405,R712,R715,R718,R721,R724,R727,R730 | R0603 | 24kΩ | 0603WAF2402T5E | UNI-ROYAL(厚声) | C23352 | LCSC
21 | 4 | 100Ω | R533,R695,R696,R697 | R0603 | 100Ω | SCR0603J100R | VO(翔胜) | C3017758 | LCSC
22 | 4 | 200Ω | R698,R700,R702,R704 | R0805 | 200Ω | FRC0805J201 TS | FOJAN(富捷) | C2933534 | LCSC
23 | 4 | 330Ω | R699,R701,R703,R705 | R0402 | 330Ω | RC0402FR-07330RL | YAGEO(国巨) | C105875 | LCSC
24 | 4 | 49.9Ω | R706,R731,R732,R733 | R0603 | 49.9Ω | 0603WAF499JT5E | UNI-ROYAL(厚声) | C23185 | LCSC
25 | 4 | 100Ω | R734,R735,R736,R737 | R0603 | 100Ω | 0603WAF1000T5E | UNI-ROYAL(厚声) | C22775 | LCSC
26 | 2 | MCP23008-E/SS | U120,U401 | SSOP-20_L7.2-W5.3-P0.65-LS7.8-BL |  | MCP23008-E/SS | MICROCHIP(美国微芯) | C148011 | LCSC
27 | 1 | ULN2803A | U122 | SOIC-18_L11.6-W7.5-P1.27-LS10.3-BL |  | ULN2803A | Mixic(中科芯亿达) | C181731 | LCSC
28 | 1 | FM24V02A-GTR | U300 | SOIC-8_L5.0-W4.0-P1.27-LS6.0-BL |  | FM24V02A-GTR | Infineon/CYPRESS(赛普拉斯) | C382041 | LCSC
29 | 1 | MCP1700T-3302E/TT | U302 | SOT-23-3_L2.9-W1.6-P1.90-LS2.8-BR |  | MCP1700T-3302E/TT | MICROCHIP(美国微芯) | C39051 | LCSC
30 | 1 | ADS1115IDGSR | U502 | MSOP-10_L3.0-W3.0-P0.50-LS5.0-BL |  | ADS1115IDGSR | TI(德州仪器) | C37593 | LCSC
31 | 1 | MCP4728-E/UN | U601 | MSOP-10_L3.0-W3.0-P0.50-LS5.0-TL |  | MCP4728-E/UN | MICROCHIP(美国微芯) | C108207 | LCSC
32 | 1 | PCA9685PW,118 | U603 | TSSOP-28_L9.7-W4.4-P0.65-LS6.4-TL | - | PCA9685PW,118 | NXP(恩智浦) | C2678753 | LCSC
33 | 4 | TMUX6209PWR | U633,U638,U640,U642 | TSSOP-16_L5.0-W4.4-P0.65-LS6.4-BL |  | TMUX6209PWR | TI(德州仪器) | C3658008 | LCSC
34 | 1 | MCP23017-E/SO | U634 | SOIC-28_L18.0-W7.5-P1.27-LS10.3-BL |  | MCP23017-E/SO | MICROCHIP(美国微芯) | C47023 | LCSC
35 | 4 | 10kΩ | U637,U639,U641,U643 | RES-ARRAY-SMD_4P-L1.6-W1.5-BL | 10kΩ | ACASN1002S1002P1AT | VISHAY(威世) | C2654064 | LCSC
36 | 4 | OPA333AIDBVR | U645,U654,U656,U658 | SOT-23-5_L3.0-W1.7-P0.95-LS2.8-BR |  | OPA333AIDBVR | TI(德州仪器) | C30878 | LCSC
37 | 4 | SN74LVC1G3157DCKR | U646,U655,U657,U659 | SC-70-6_L2.2-W1.3-P0.65-LS2.1-BR |  | SN74LVC1G3157DCKR | TI(德州仪器) | C38663 | LCSC

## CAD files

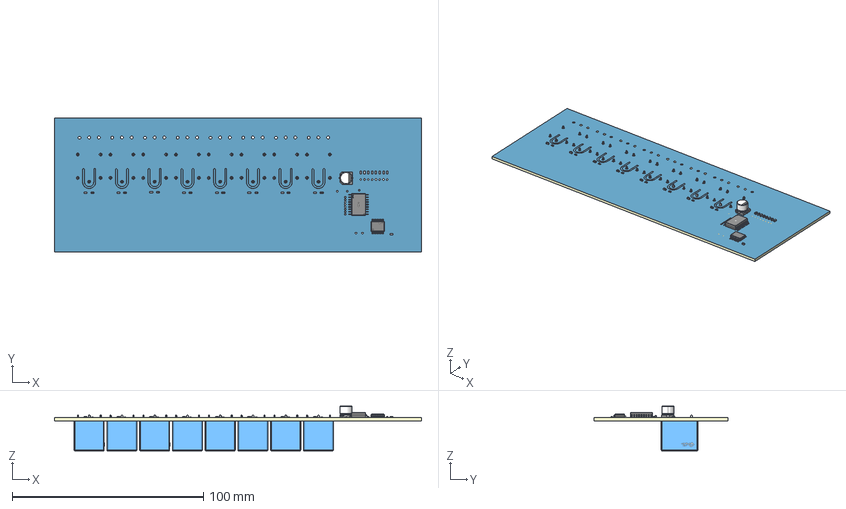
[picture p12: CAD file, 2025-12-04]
docs/Renderings/3D Models/3D_PCB11_2025-08-22.step
192.1 x 70.2 x 23.5 mm
Board~OImK
TopCopper~OImK
BottomCopper~OImK
TopFpcStiffener~OImK
BottomFpcStiffener~OImK
C0603~C0603_L1.6-W0.8-H0.8~OImK
R21~R0603~R0603~OImK x 17
CAP-SMD_BD6.3-L6.6-W6.6-LS7.6-RD~CAP-SMD_BD6.3-L6.6-W6.6-LS7.6-RD~OImK
RELAY-TH_SRD-XXVDC-XL-C~RELAY-TH_L19.2-W15.6-H15.8~OImK x 8
SOIC-18_L11.6-W7.5-P1.27-LS10.3-BL~SOIC-18_ L11.6-W7.5-H2.7-LS10.3-P1.27~OImK
LED0603-RD_BLUE~LED0603-RD_BLUE~OImK x 8
SSOP-20_L7.2-W5.3-P0.65-LS7.8-BL~SSOP-20_L7.2-W5.3-P0.65-LS7.8~OImK

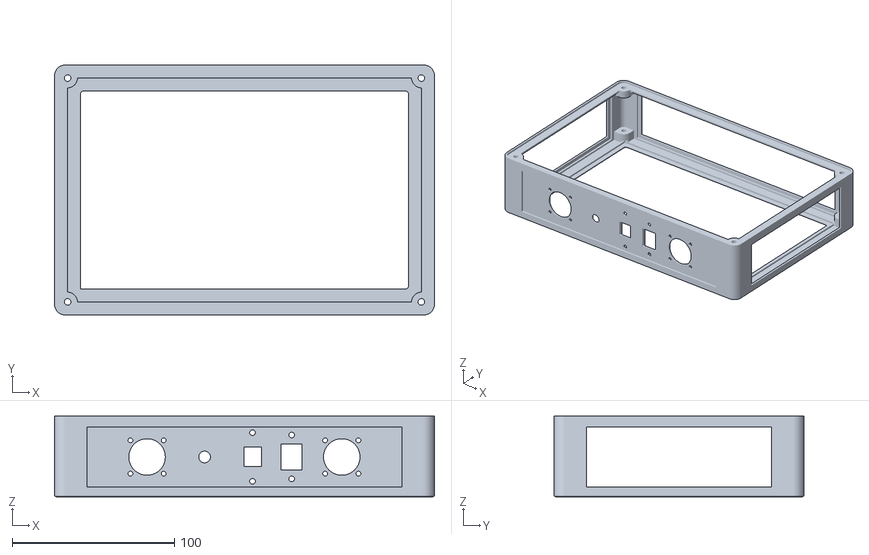
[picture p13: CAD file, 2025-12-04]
hardware/Enclosure/Board v13a.stl
234.0 x 154.0 x 49.6

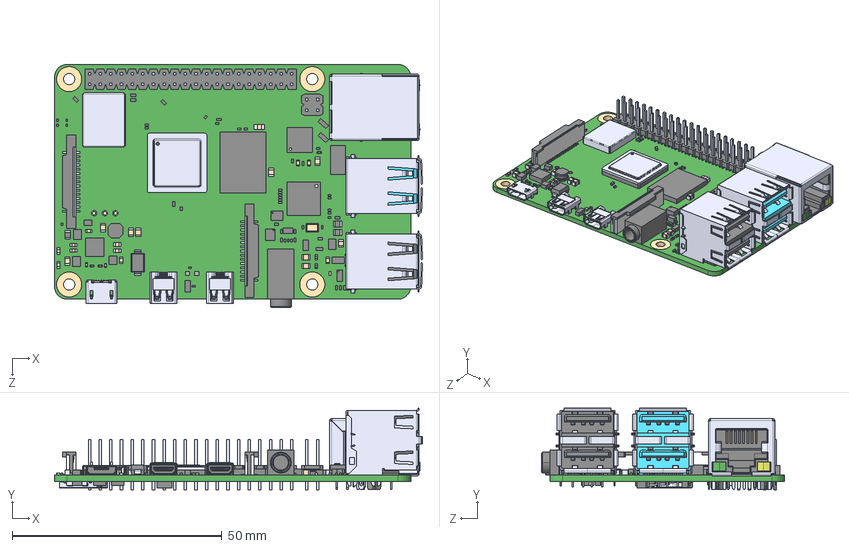
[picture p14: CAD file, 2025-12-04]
hardware/Main/Archieve/RASPBERRY_PI_4B_4GB.step
87.8 x 19.5 x 58.0 mm

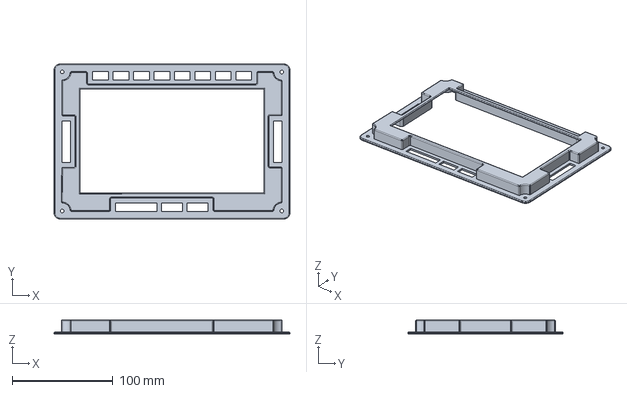
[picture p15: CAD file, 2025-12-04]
hardware/overlay/Enclosure v2b.step
234.0 x 154.0 x 14.0 mm

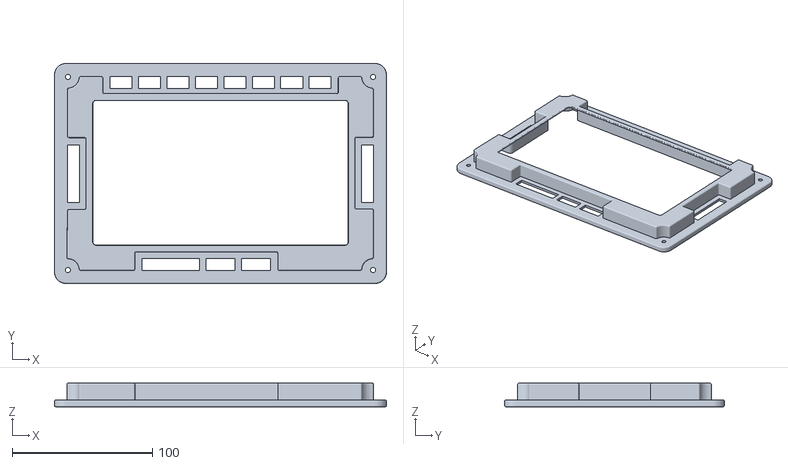
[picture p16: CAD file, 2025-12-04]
hardware/Enclosure/Board v13b.stl
237.0 x 157.0 x 17.0

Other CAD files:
hardware/Release Files/V1 - 2025-09-09/Enclosure/Board v13a.step
hardware/Release Files/V1 - 2025-09-09/Enclosure/Board v13b.step

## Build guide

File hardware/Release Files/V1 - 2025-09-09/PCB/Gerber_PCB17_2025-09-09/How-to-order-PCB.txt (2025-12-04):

How to Order PCB

Please refer to:
https://prodocs.easyeda.com/en/pcb/order-order-pcb/index.html

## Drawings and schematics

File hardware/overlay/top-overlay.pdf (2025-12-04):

# Relay Outputs

R1

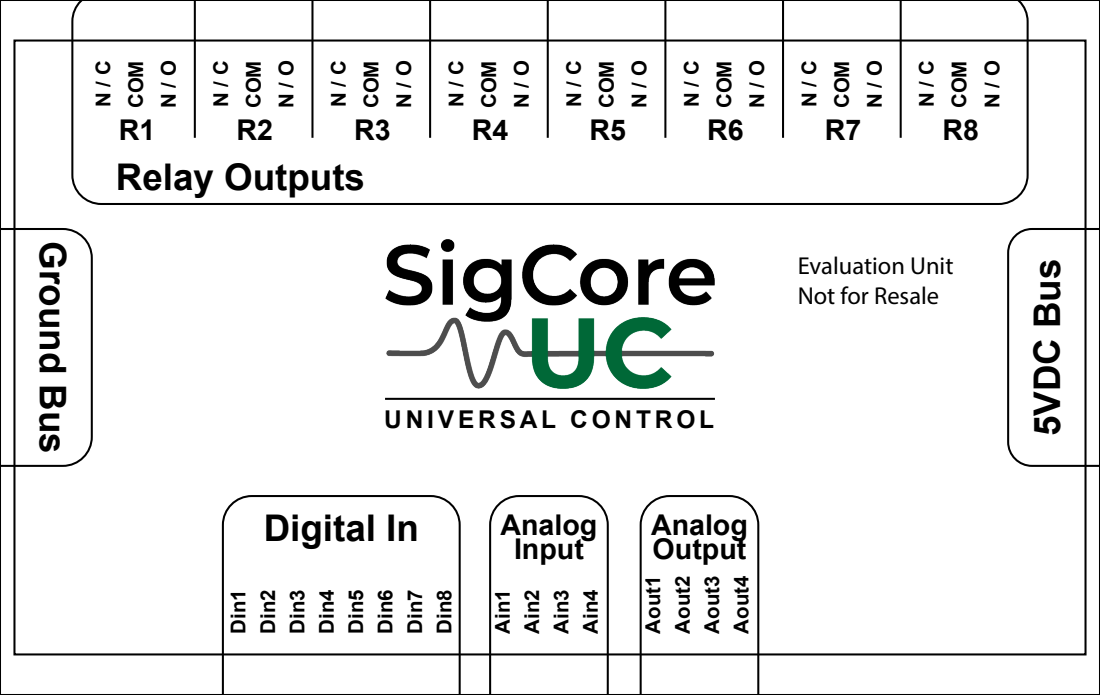
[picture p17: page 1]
COM; Digital In; Din1; Din2; Din3; Din4; Din5; Din6; Din7; Din8; Analog Input; Ain1; Ain2; Ain3; Ain4; Analog; Output Aout1 Aout2 Aout3 Aout4; Ground Bus; UNIVERSAL CONTROL; 5VDC Bus

Evaluation Unit
Not for Resale

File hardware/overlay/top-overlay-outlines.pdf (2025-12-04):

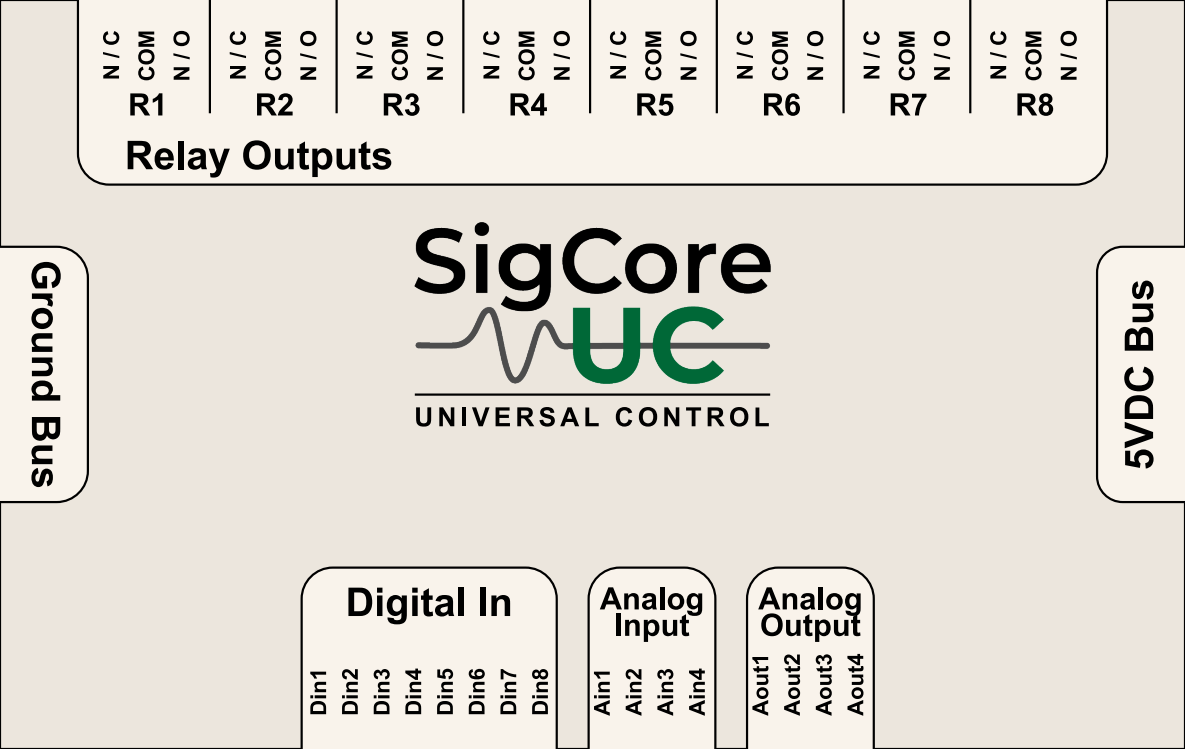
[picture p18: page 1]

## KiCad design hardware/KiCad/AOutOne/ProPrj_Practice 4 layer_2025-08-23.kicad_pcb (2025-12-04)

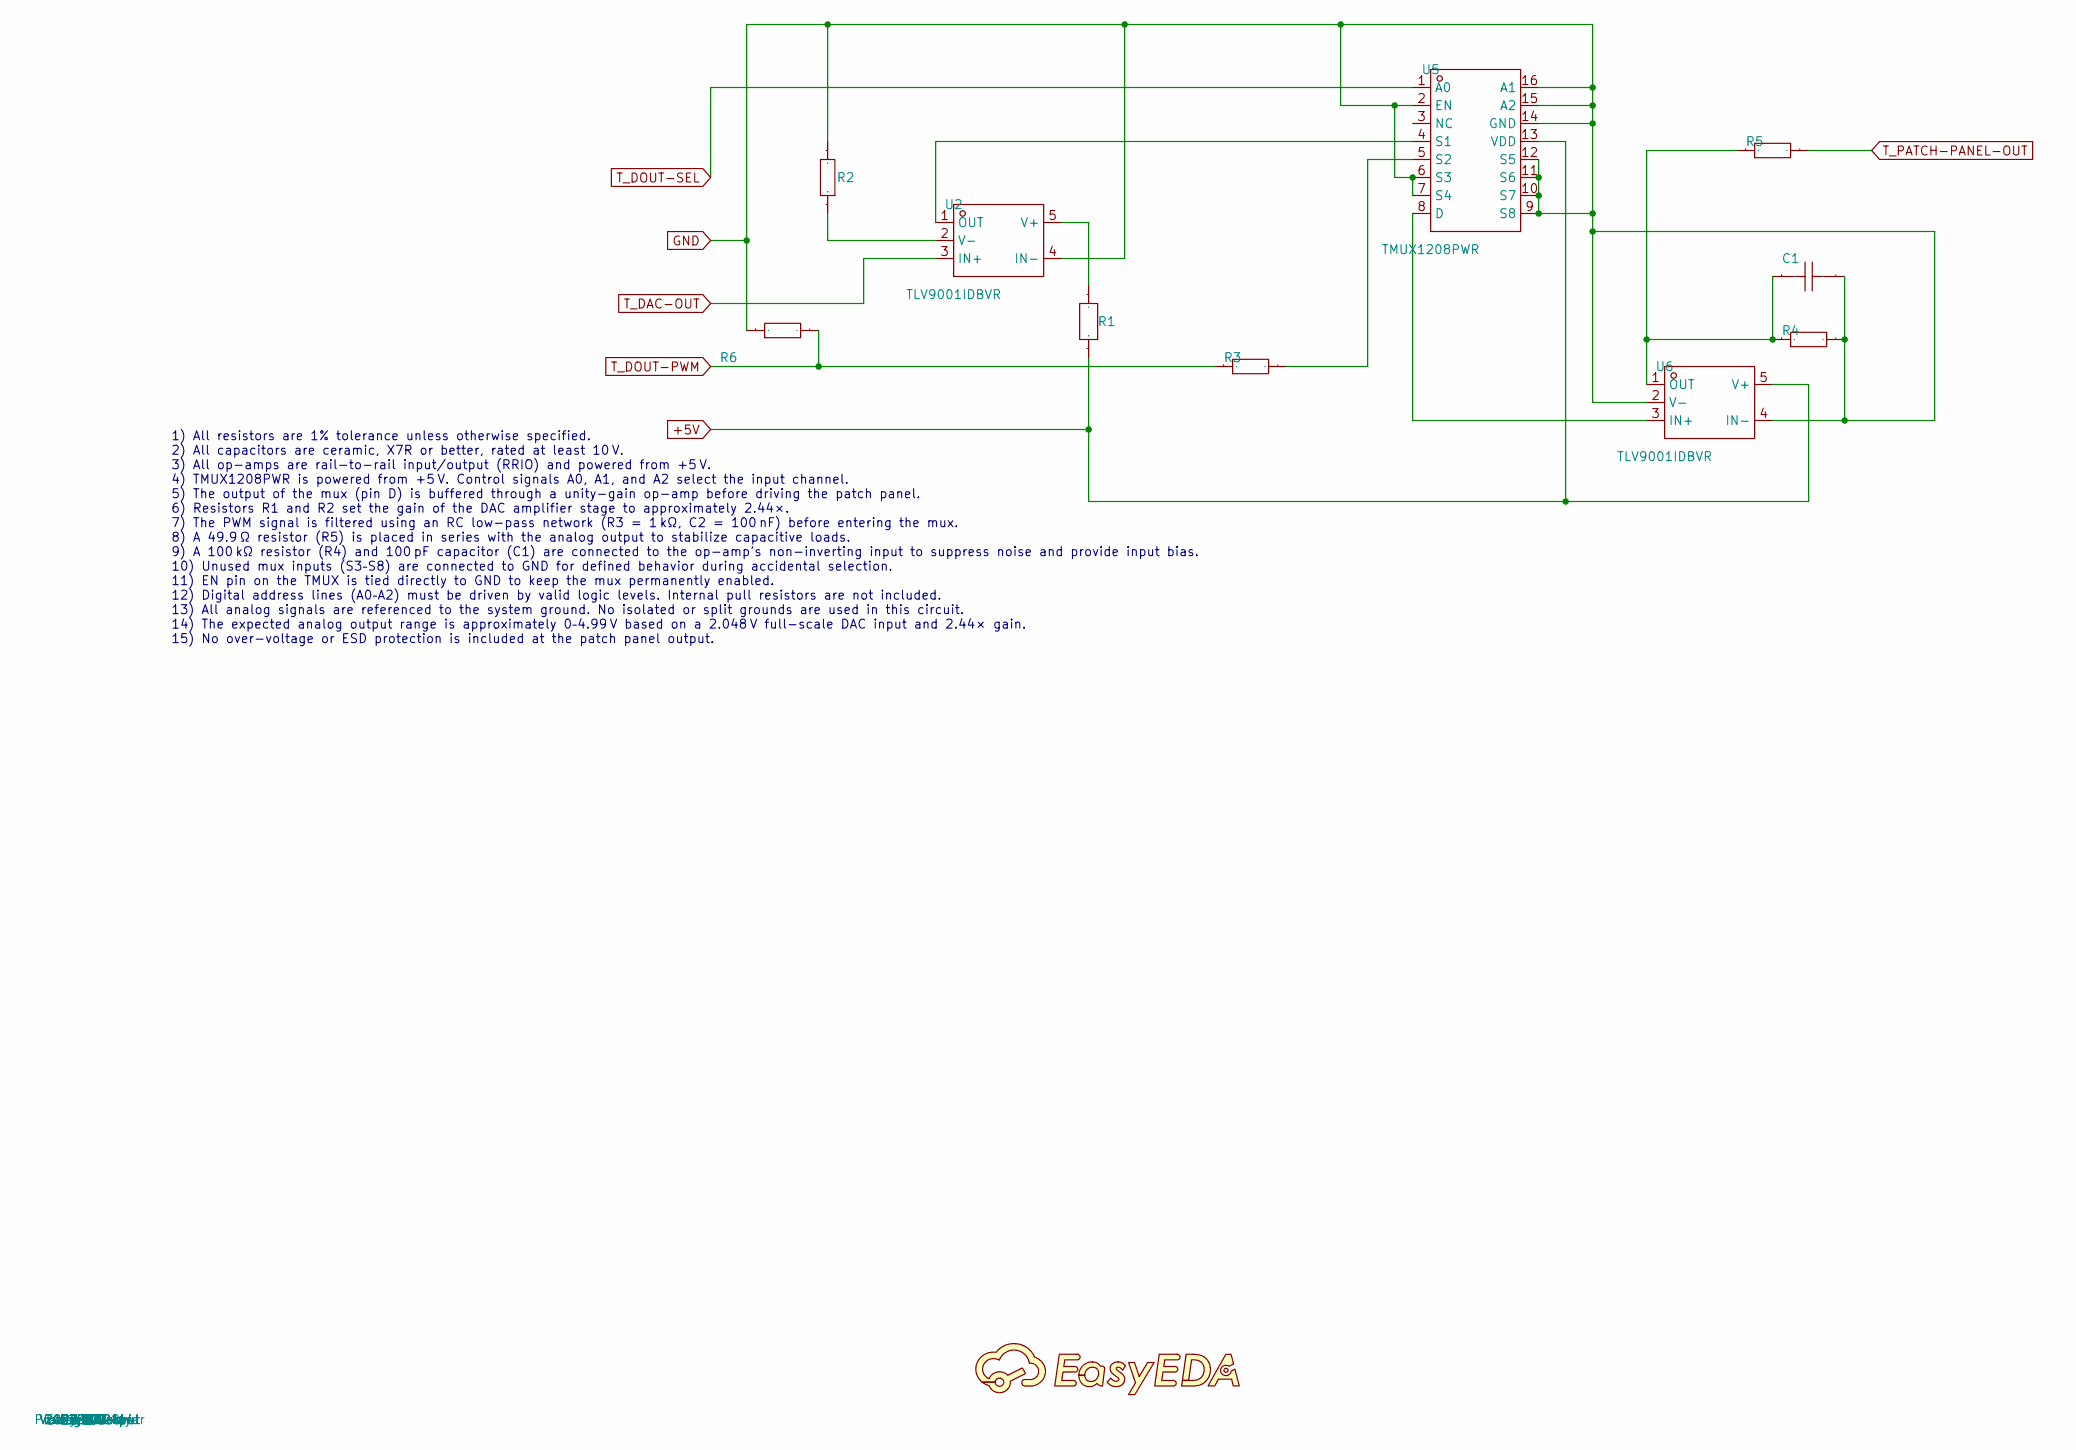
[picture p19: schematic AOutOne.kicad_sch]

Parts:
C1: 100pF; C0603; Manufacturer Part CC0603JRNPO9BN101; LCSC Part Name 100pF ±5% 50V
R1: 30.9kΩ; R0603; Manufacturer Part FRC0603F3092TS; LCSC Part Name 30.9kΩ ±1% 100mW 厚膜电阻
R2: 21.5kΩ; R0402; Manufacturer Part 0402WGF2152TCE; LCSC Part Name 21.5kΩ ±1% 62.5mW 厚膜电阻
R3: 1kΩ; R0603; Manufacturer Part 0603WAJ0102T5E; LCSC Part Name 1kΩ ±5% 100mW 厚膜电阻
R4, R6: 100kΩ; R0603; Manufacturer Part 0603WAF1003T5E; LCSC Part Name 100kΩ ±1% 100mW 厚膜电阻
R5: 49.9Ω; R0603; Manufacturer Part 0603WAF499JT5E; LCSC Part Name 49.9Ω ±1% 100mW 厚膜电阻
U2, U6: TLV9001IDBVR; SOT-23-5_L3.0-W1.7-P0.95-LS2.8-BR; Manufacturer Part TLV9001IDBVR; LCSC Part Name TLV9001IDBVR
U5: TMUX1208PWR; TSSOP-16_L5.0-W4.4-P0.65-LS6.4-BL; Manufacturer Part TMUX1208PWR; LCSC Part Name TMUX1208 5V 双向8:1单通道多路复用器

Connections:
+5V: R1.1, U5.13 (VDD), U6.5 (V+)
GND: C1.2, R2.2, R4.2, R6.1, U2.4 (IN-), U5.2 (EN), U5.6 (S3), U5.7 (S4), U5.9 (S8), U5.10 (S7), U5.11 (S6), U5.12 (S5), U5.14 (GND), U5.15 (A2), U5.16 (A1), U6.2 (V-), U6.4 (IN-)
T_DAC-OUT: U2.3 (IN+)
T_DOUT-PWM: R3.1, R6.2
T_DOUT-SEL: U5.1 (A0)
T_PATCH-PANEL-OUT: R5.2
T_U2V+: R1.2, U2.5 (V+)
T_U2V-: R2.1, U2.2 (V-)
T_U5D: U5.8 (D), U6.3 (IN+)
T_U5S1: U2.1 (OUT), U5.4 (S1)
T_U5S2: R3.2, U5.5 (S2)
T_U6OUT: C1.1, R4.1, R5.1, U6.1 (OUT)

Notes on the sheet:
1) All resistors are 1% tolerance unless otherwise specified. 2) All capacitors are ceramic, X7R or better, rated at least 10 V. 3) All op-amps are rail-to-rail input/output (RRIO) and powered from +5 V. 4) TMUX1208PWR is powered from +5 V. Control signals A0, A1, and A2 select the input channel. 5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

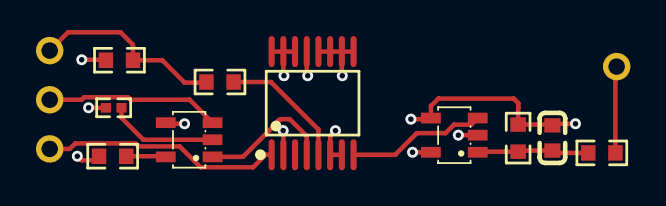
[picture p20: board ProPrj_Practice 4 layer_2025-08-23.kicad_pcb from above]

Board: 4 copper layers, 10 parts (0 on the bottom side), 9 nets.

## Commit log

2025-12-04 Initial clean commit
    [3D_PCB11_2025-08-22.step, AInOne.kicad_sch, AInTop.kicad_sch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]
2025-12-24 Minor housekeeping
    [Contacts.xlsx]
2025-12-25 Remove marketing and accounting files
    [Budget.xlsx, Contacts.xlsx]
2026-01-15 Current State
